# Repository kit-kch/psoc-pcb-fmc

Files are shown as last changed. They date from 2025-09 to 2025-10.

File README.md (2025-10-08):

# PSoC FMC Extension PCB

This repository contains schematic, layout and BOM for the PSoC FMC extension PCB.
The PCB provides all peripherals that are used to realize the [PSoC Audio Player](https://kch.dev/psoc).
It is primarily meant to be used with the Zedboard for FPGA prototyping, but it can also serve as a test board for the PSoC ASIC.

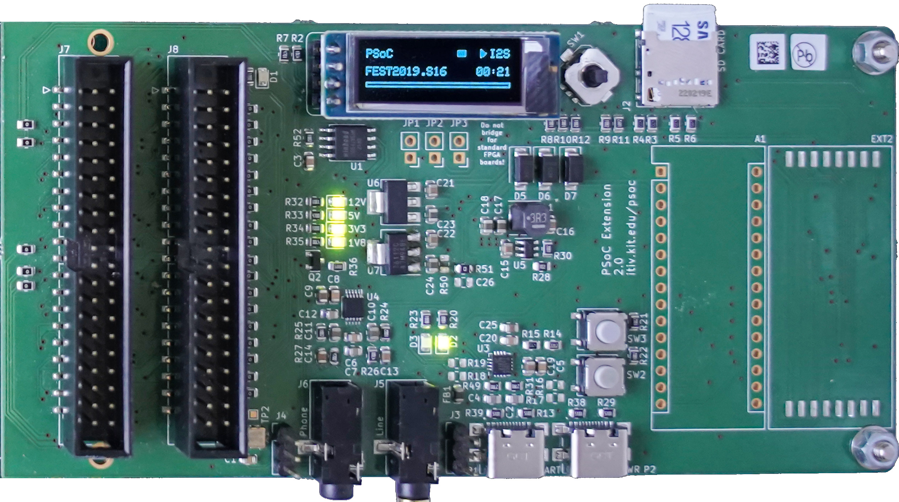
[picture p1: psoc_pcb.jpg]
PCB Render Image


The following features are provided by the PCB:
* 98.304 MHz oscillator ([XLH53V098.304000X](doc/REN_XL_Crystal_Oscillators_Datasheet_DST_20220302-1954959-1.pdf)) for SoC clock
* 64 MBit QSPI Flash ([W25Q64JVSSIM](doc/w25q64jv_dtr_revj_03272018_plus-1489809.pdf))
* USB/UART bridge ([CP2102N](doc/cp2102n_datasheet-1634912.pdf))
* 3 LEDs
* 2 [push buttons](doc/EVPBF.pdf)
* [5-way digital joystick](doc/SKRHAAE010.pdf)
* 128x32 [OLED display](https://www.waveshare.com/0.91inch-oled-module.htm) (I2C)
* I2S DAC with output filter networks ([CS4344-CZZR](doc/CS4344-45-48_F2.pdf))
* [3.5mm audio jack](doc/sj_352x_smt-1779397.pdf) for I2S DAC
* [3.5mm audio jack](doc/sj_352x_smt-1779397.pdf) directly connected to FMC
* [MicroSD card connector](doc/MOLEX_472192001_sd.pdf) (1-bit data line only)
* Power switch network: Power PCB from FMC 12V, power connector or UART usb connector
* 5V power regulator ([AP62300WU](doc/AP62300_AP62301_AP62300T.pdf))
* 3.3V power regulator (AMS1117-3.3)
* 1.8V power regulator (LM1117MPX-ADJ)
* Power indicator LEDs
* [USB-C connector](doc/usb4110.pdf) for UART
* [USB-C connector](doc/usb4110.pdf) for power
* [FMC LPC connector](doc/asp-134604-01-mkt-1546032.pdf) to connect to FPGA or ASIC
* 2 [40-pin pin headers](doc/SBH11-NBPC.pdf) for debugging of any signal
* Connector for future extensions (based on KiCAD RFM69HW footprint)
* Arduino-like connector for future extensions

For more details, see the [schematic](psoc.pdf):

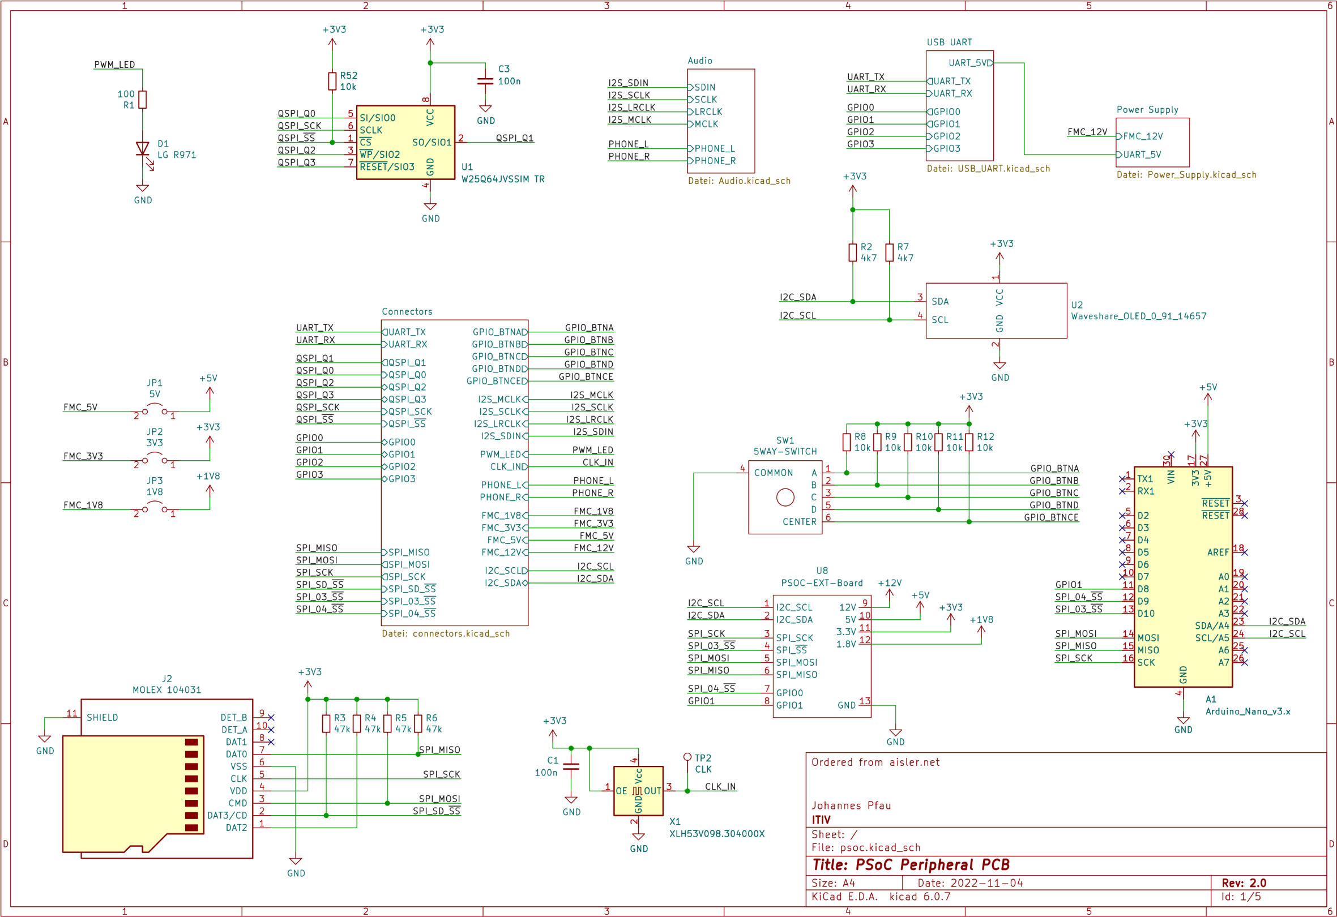
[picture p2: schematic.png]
PCB Schematic


## Ordering the PCBs

PCBs were ordered from [aisler.net](https://aisler.net) using the [fab.zip](fab.zip) file.
Make sure to use a stencil with 150µm thickness for proper FMC connector soldering.

## More Information and Documentation

* Project Website and Documentation: [kch.dev/psoc](https://kch.dev/psoc)
* Project Schematic: [psoc.pdf](psoc.pdf)

Additional documentation:
* [FMC Documentation](https://fmchub.github.io/appendix/VITA57_FMC_HPC_LPC_SIGNALS_AND_PINOUT.html)
* [USB-C Termination](https://community.cypress.com/t5/Knowledge-Base-Articles/Termination-Resistors-Required-for-the-USB-Type-C-Connector/ta-p/253544)
* [Audio TRS Standard](https://components101.com/connectors/35mm-audio-jack)

## Note and Limitations

### JTAG

* The board unfortunately does not provide convenient access to JTAG pins, although the debug header can be used.
  As a workaround, [psoc-pcb-jtag](https://github.com/kit-kch/psoc-pcb-jtag) can be connected to the USB header.

### Powering the IHP ASIC

The [IHP SG13G2 ASIC](https://github.com/IHP-GmbH/TO_Sep2025/pull/4) requires an 1.2V source instead of the 1.8V on this board.
Although the regulator on the board is adjustable, it can't go down to 1.2V.

As a simple solution, some parts can be replaced to provide 1.2V output:
* `U7` with `TLV76112DCYR` 1A 1.2V regulator
* `R51` with 0 Ohm (short)
* Remove `R50`
* Remove `C26`

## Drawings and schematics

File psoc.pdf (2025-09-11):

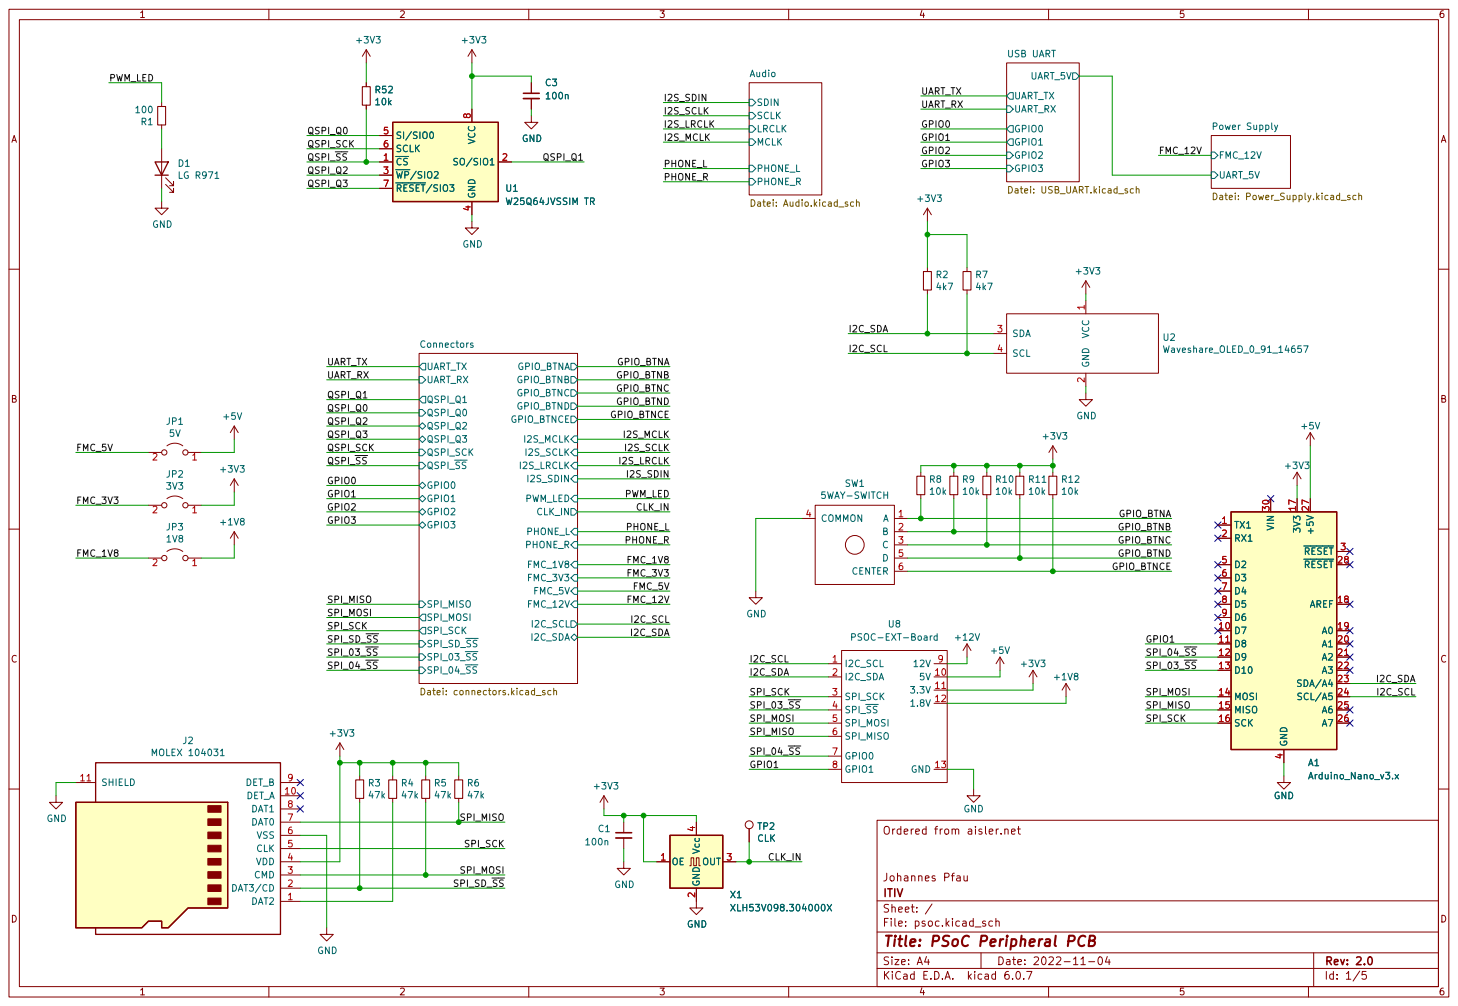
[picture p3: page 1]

4 SI/SIO0 5 SCLK 6 ~{RESET}/SIO3 7 VCC

12V 9 U8 PSOC-EXT-Board GND
I2C_SDA

Johannes Pfau Ordered from aisler.net

ITIV
File: psoc.kicad_sch Sheet: /
Id: 1/5 Title: PSoC Peripheral PCB

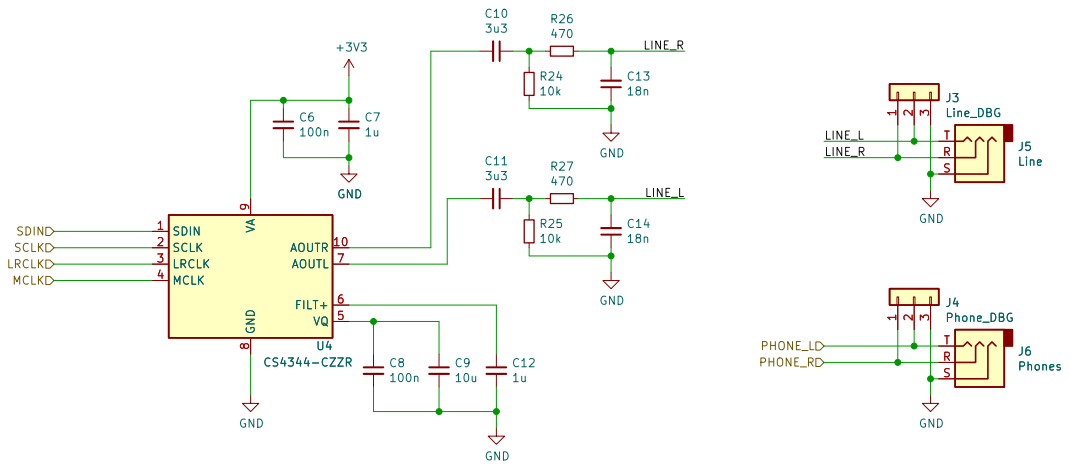
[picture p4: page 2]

LINE_L
File: Audio.kicad_sch Sheet: /Audio/ GND

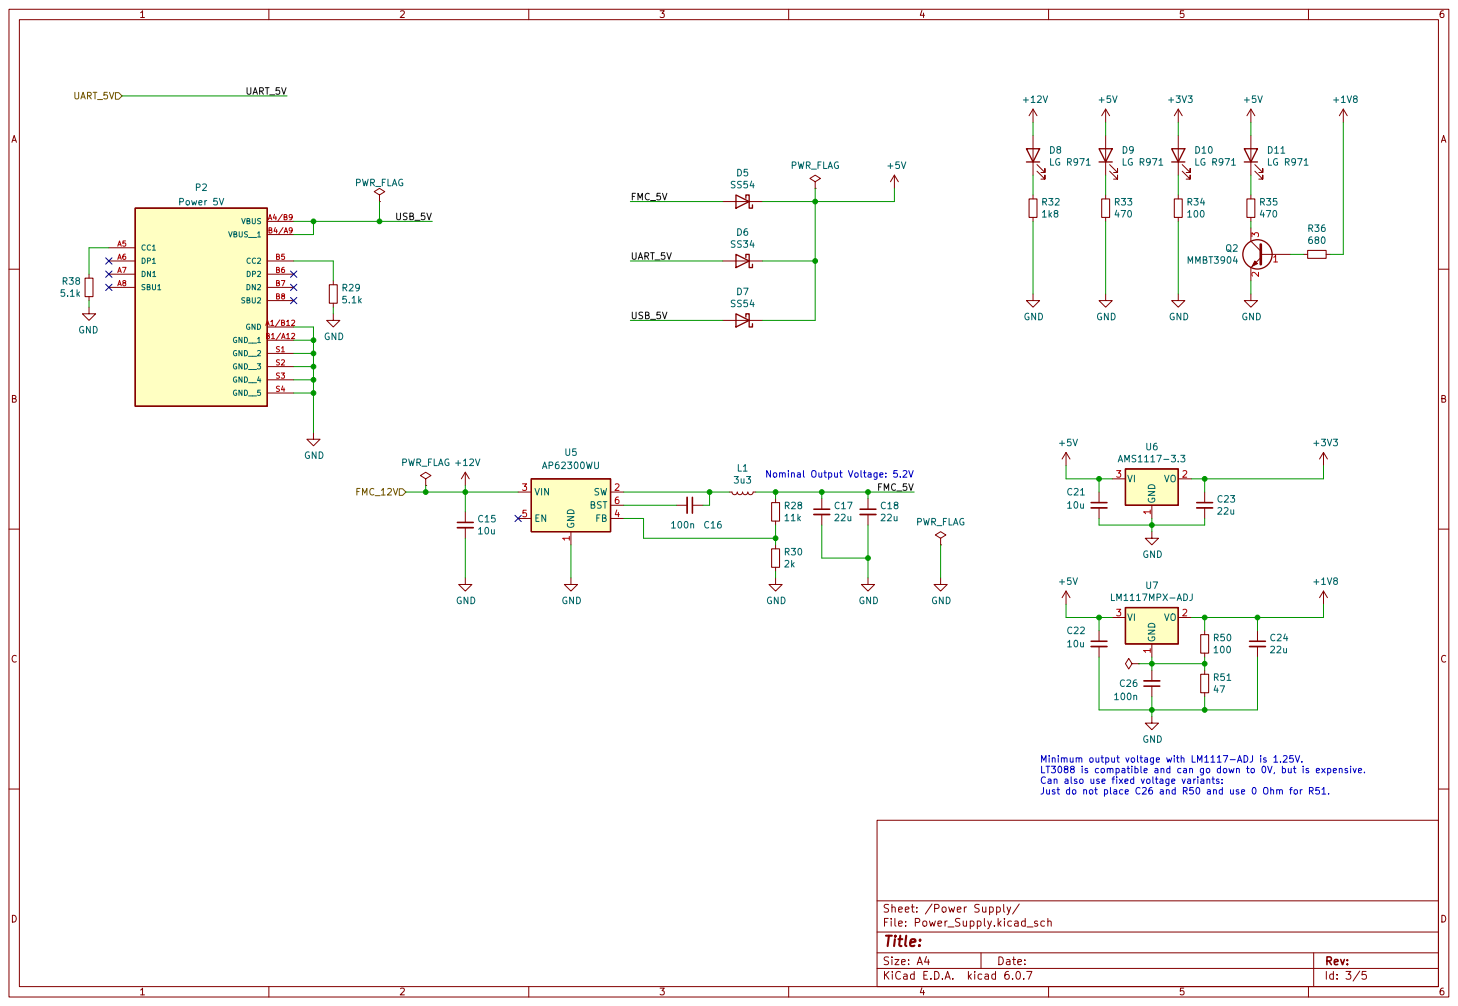
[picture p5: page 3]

1 SW 2 VIN 3 FB 4 EN 5 BST 6 U5 AP62300WU

Minimum output voltage with LM1117-ADJ is 1.25V.
LT3088 is compatible and can go down to 0V, but is expensive.
Can also use fixed voltage variants:
Just do not place C26 and R50 and use 0 Ohm for R51.

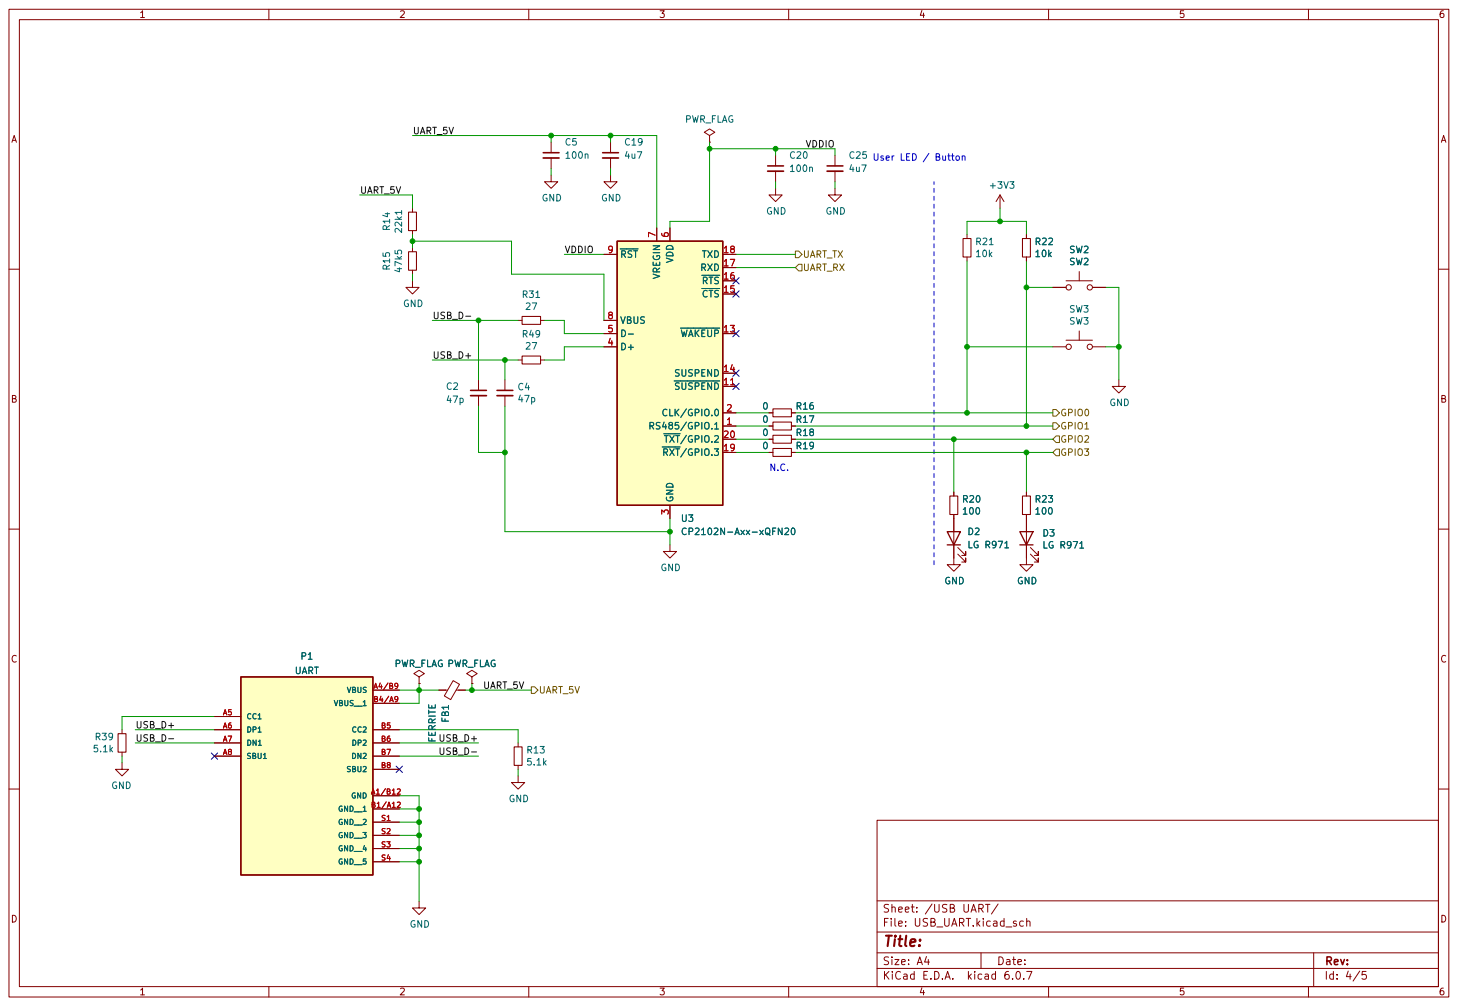
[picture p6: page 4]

7 VBUS 8 ~{RST} 9 P1 UART GND A1/B12 VBUS A4/B9 CC1 A5 DP1 A6 DN1 A7 SBU1 A8 GND__1 B1/A12 VBUS__1 B4/A9 CC2 B5 DP2 B6 DN2 B7 SBU2 B8 GND__2 S1 GND__3 S2 GND__4 S3 GND__5 S4

File: USB_UART.kicad_sch Sheet: /USB UART/ GND

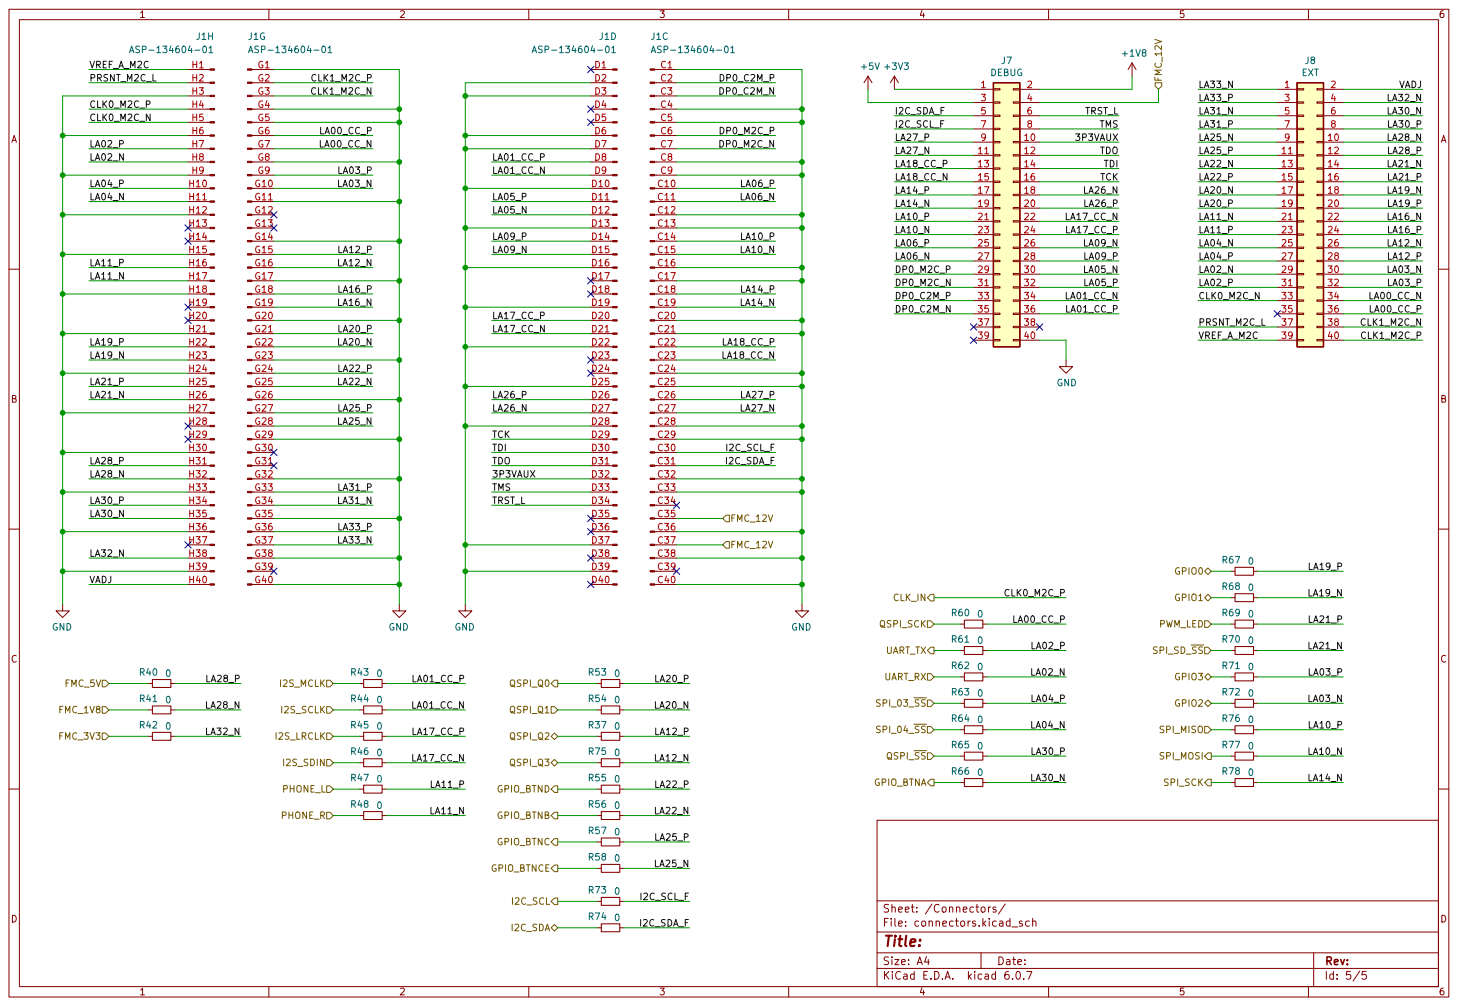
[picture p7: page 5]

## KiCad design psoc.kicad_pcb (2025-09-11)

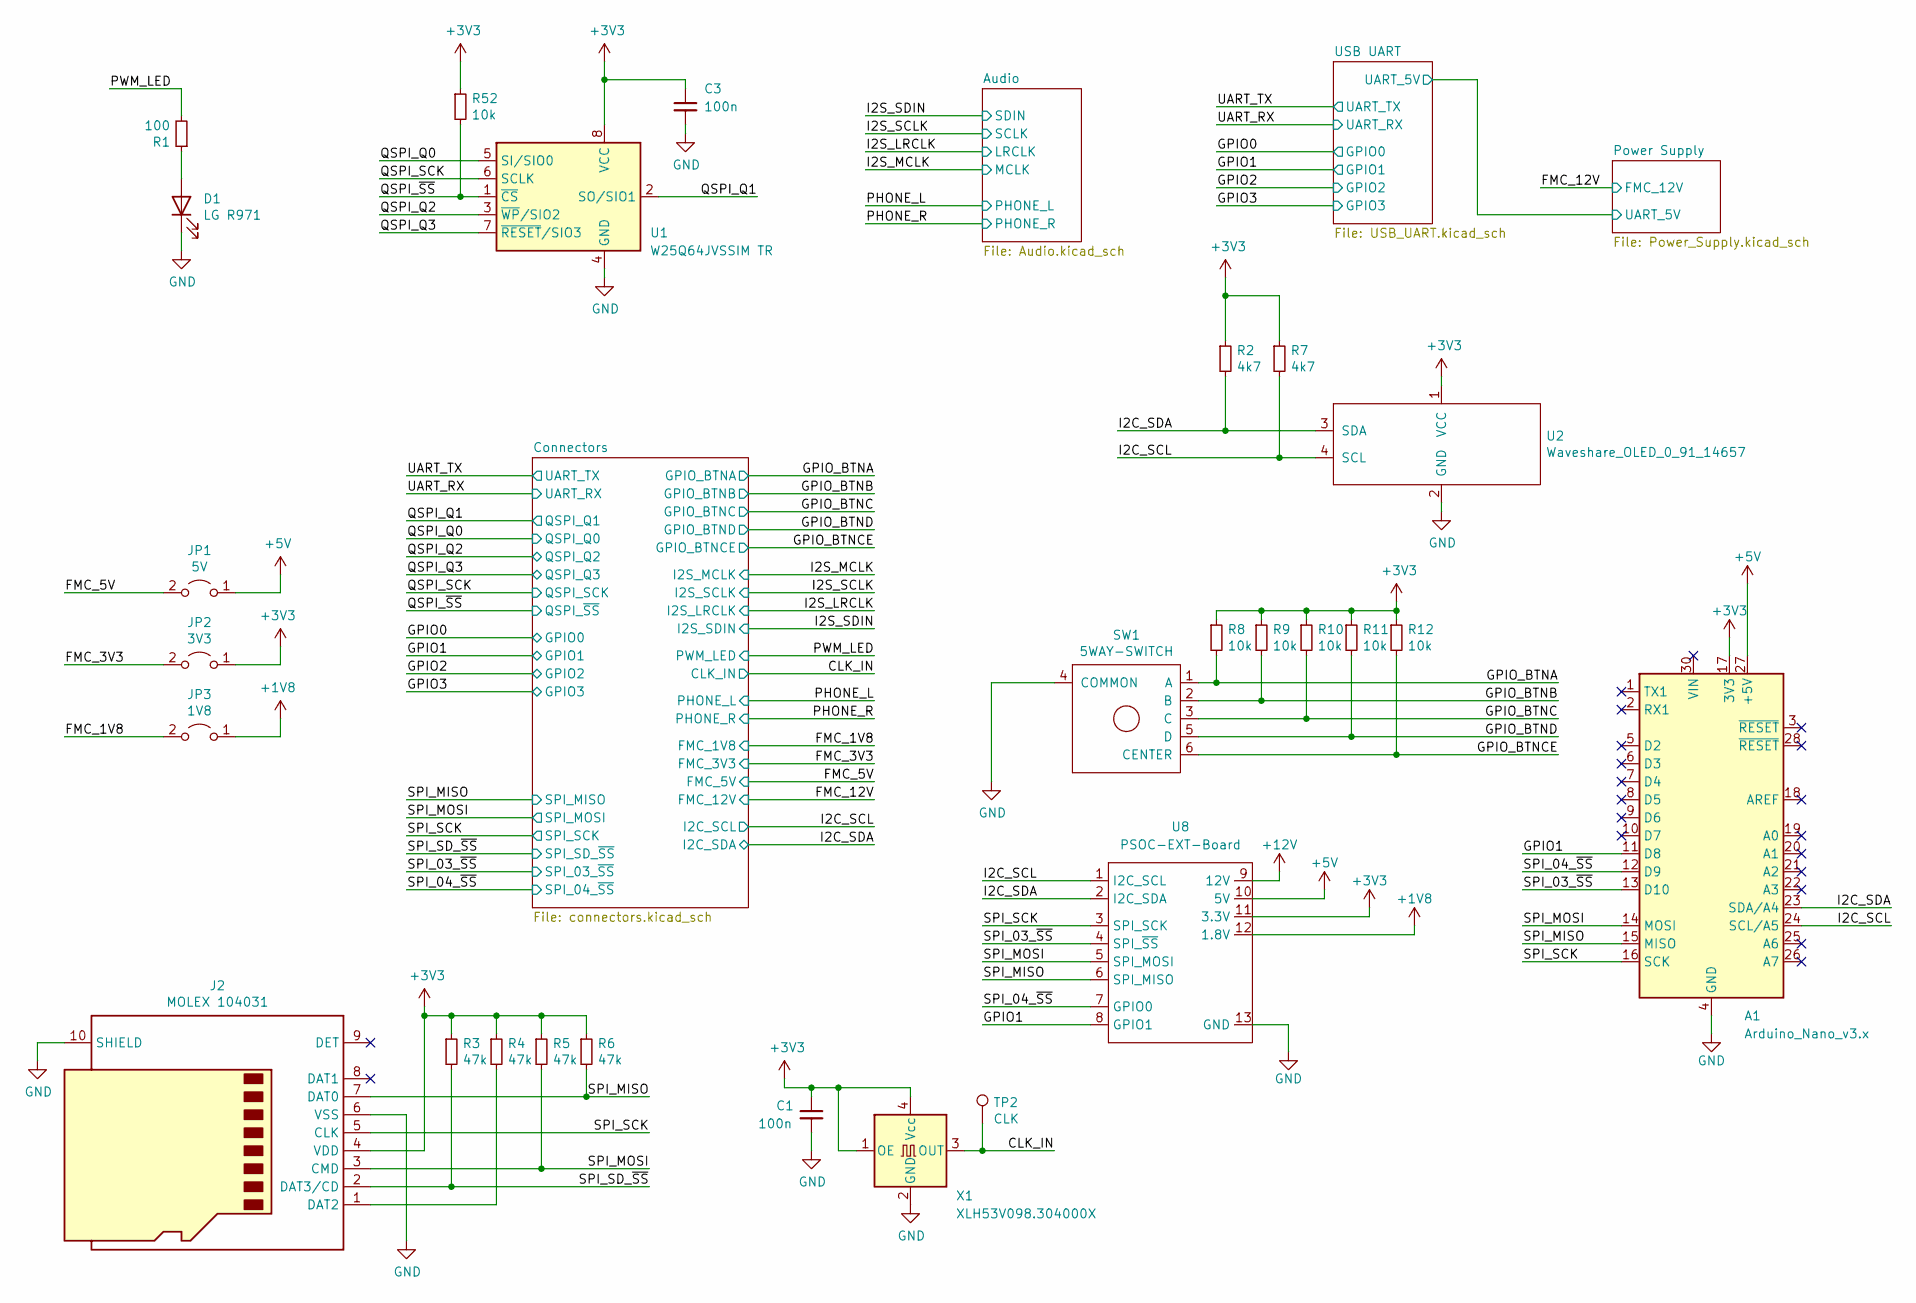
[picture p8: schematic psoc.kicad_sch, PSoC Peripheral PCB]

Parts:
A1: Arduino_Nano_v3.x; Arduino_Nano
C1, C3: 100n; C_0805_2012Metric; MPN 100nF 0805
D1: LG R971; LED_0805_2012Metric; MPN LG R971-KN-1
J2: MOLEX 104031; microSD_HC_Molex_104031-0811; MPN 1040310811
JP1: 5V; PinHeader_1x02_P2.54mm_Vertical; MPN 2302-6111TG
JP2: 3V3; PinHeader_1x02_P2.54mm_Vertical; MPN 2302-6111TG
JP3: 1V8; PinHeader_1x02_P2.54mm_Vertical; MPN 2302-6111TG
R1: 100; R_0805_2012Metric; MPN 0805 100
R2, R7: 4k7; R_0805_2012Metric; MPN 4k7 0805
R3, R4, R5, R6: 47k; R_0805_2012Metric; MPN 47k 0805
R8, R9, R10, R11, R12, R52: 10k; R_0805_2012Metric; MPN 10k 0805
SW1: 5WAY-SWITCH; SKRHAAE010; MPN SKRHAAE010
TP2: CLK; TestPoint_Pad_1.0x1.0mm
U1: W25Q64JVSSIM TR; SOIC-8_5.3x5.3mm_P1.27mm; MPN W25Q64JVSSIM TR
U2: Waveshare_OLED_0_91_14657; Waveshare_OLED_091
U8: PSOC-EXT-Board; PSOC_EXT_BOARD
X1: XLH53V098.304000X; Oscillator_SMD_Renesas_LGA-6_5x3.2mm_P1.25mm; MPN XLH53V098.304000X

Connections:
+1V8: JP3.1 (A), U8.12 (1.8V); also elsewhere on the board
+3V3: A1.17 (3V3), C1.1, C3.1, J2.4 (VDD), JP2.1 (A), R2.1, R3.1, R4.1, R5.1, R6.1, R7.1, R8.1, R9.1, R10.1, R11.1, R12.1, R52.1, U1.8 (VCC), U2.1 (VCC), U8.11 (3.3V), X1.1 (OE), X1.4 (Vcc); also elsewhere on the board
+5V: A1.27 (+5V), JP1.1 (A), U8.10 (5V); also elsewhere on the board
+12V: U8.9 (12V); also elsewhere on the board
/CLK_IN: TP2.1, X1.3 (OUT); also elsewhere on the board
/FMC_1V8: JP3.2 (B); also elsewhere on the board
/FMC_3V3: JP2.2 (B); also elsewhere on the board
/FMC_5V: JP1.2 (B); also elsewhere on the board
/GPIO1: A1.11 (D8), U8.8 (GPIO1); also elsewhere on the board
/GPIO_BTNA: R8.2, SW1.1 (A); also elsewhere on the board
/GPIO_BTNB: R9.2, SW1.2 (B); also elsewhere on the board
/GPIO_BTNC: R10.2, SW1.3 (C); also elsewhere on the board
/GPIO_BTNCE: R12.2, SW1.6 (CENTER); also elsewhere on the board
/GPIO_BTND: R11.2, SW1.5 (D); also elsewhere on the board
/I2C_SCL: A1.24 (SCL/A5), R7.2, U2.4 (SCL), U8.1 (I2C_SCL); also elsewhere on the board
/I2C_SDA: A1.23 (SDA/A4), R2.2, U2.3 (SDA), U8.2 (I2C_SDA); also elsewhere on the board
/PWM_LED: R1.2; also elsewhere on the board
/QSPI_Q0: U1.5 (SI/SIO0); also elsewhere on the board
/QSPI_Q1: U1.2 (SO/SIO1); also elsewhere on the board
/QSPI_Q2: U1.3 (~WP/SIO2); also elsewhere on the board
/QSPI_Q3: U1.7 (~RESET/SIO3); also elsewhere on the board
/QSPI_SCK: U1.6 (SCLK); also elsewhere on the board
/QSPI_~SS: R52.2, U1.1 (~CS); also elsewhere on the board
/SPI_03_~SS: A1.13 (D10), U8.4 (SPI_~SS); also elsewhere on the board
/SPI_04_~SS: A1.12 (D9), U8.7 (GPIO0); also elsewhere on the board
/SPI_MISO: A1.15 (MISO), J2.7 (DAT0), R6.2, U8.6 (SPI_MISO); also elsewhere on the board
/SPI_MOSI: A1.14 (MOSI), J2.3 (CMD), R5.2, U8.5 (SPI_MOSI); also elsewhere on the board
/SPI_SCK: A1.16 (SCK), J2.5 (CLK), U8.3 (SPI_SCK); also elsewhere on the board
/SPI_SD_~SS: J2.2 (DAT3/CD), R3.2; also elsewhere on the board
GND: A1.4 (GND), A1.29 (GND), C1.2, C3.2, D1.1 (K), J2.6 (VSS), J2.10 (SHIELD), J2.11 (SHIELD), SW1.4 (COMMON), U1.4 (GND), U2.2 (GND), U8.13 (GND), X1.2 (GND); also elsewhere on the board
unnamed: D1.2 (A), R1.1
unnamed: J2.1 (DAT2), R4.2

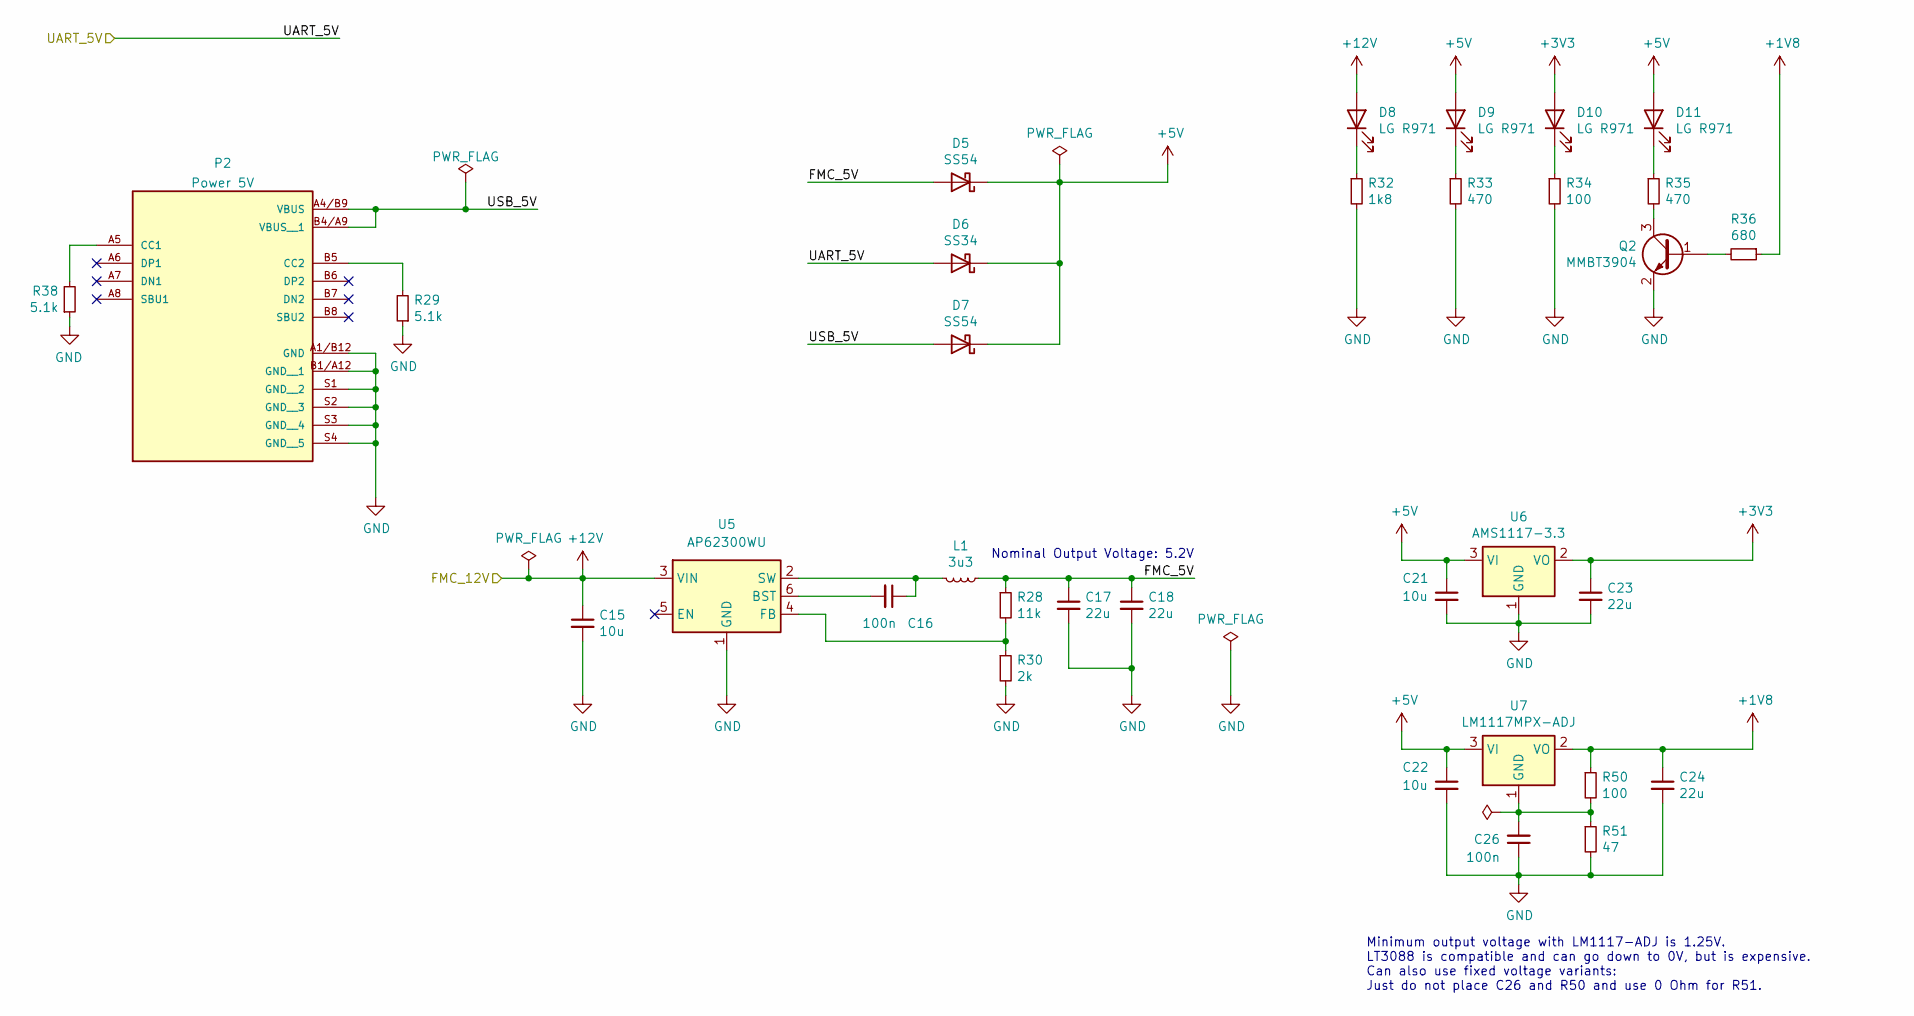
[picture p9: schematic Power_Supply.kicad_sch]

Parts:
C15, C21, C22: 10u; C_0805_2012Metric; MPN 10uF 0805 25V
C16, C26: 100n; C_0805_2012Metric; MPN 100nF 0805
C17, C18, C23, C24: 22u; C_0805_2012Metric; MPN 22uF 0805
D5, D7: SS54; D_SMA; MPN SS54
D6: SS34; D_SMA; MPN SS34
D8, D9, D10, D11: LG R971; LED_0805_2012Metric; MPN LG R971-KN-1
L1: 3u3; L_Taiyo-Yuden_NR-50xx; MPN NRS5040T3R3NMGJ
P2: Power 5V; GCT_USB4110-GF-A_REVB; MPN USB4110-GF-A
Q2: MMBT3904; SOT-23; MPN MMBT3904Q-7-F
R28: 11k; R_0805_2012Metric; MPN 11k 0805
R29, R38: 5.1k; R_0805_2012Metric; MPN 5k1 0805
R30: 2k; R_0805_2012Metric; MPN 2k 0805
R32: 1k8; R_0805_2012Metric; MPN 1k8 0805
R33, R35: 470; R_0805_2012Metric; MPN 0805 470
R34: 100; R_0805_2012Metric; MPN 0805 100
R36: 680; R_0805_2012Metric; MPN 0805 680
R50: 100; R_0805_2012Metric; MPN 100 0805
R51: 47; R_0805_2012Metric; MPN 47 0805
U5: AP62300WU; TSOT-23-6; MPN AP62301WU-7
U6: AMS1117-3.3; TO-252-3_TabPin2; MPN AZ1117IH-3.3TRG1
U7: LM1117MPX-ADJ; TO-252-3_TabPin2; MPN LM1117MPX-ADJNOPB

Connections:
+1V8: C24.1, R36.1, R50.1, U7.2 (VO); also elsewhere on the board
+3V3: C23.1, D10.2 (A), U6.2 (VO); also elsewhere on the board
+5V: C21.1, C22.1, D5.1 (K), D6.1 (K), D7.1 (K), D9.2 (A), D11.2 (A), U6.3 (VI), U7.3 (VI); also elsewhere on the board
+12V: C15.1, D8.2 (A), U5.3 (VIN); also elsewhere on the board
/Power Supply/FMC_5V: C17.1, C18.1, D5.2 (A), L1.1, R28.1
/Power Supply/UART_5V: D6.2 (A); also elsewhere on the board
/Power Supply/USB_5V: D7.2 (A), P2.A4/B9 (VBUS), P2.B4/A9 (VBUS__1)
GND: C15.2, C17.2, C18.2, C21.2, C22.2, C23.2, C24.2, C26.1, P2.A1/B12 (GND), P2.B1/A12 (GND__1), P2.S1 (GND__2), P2.S2 (GND__3), P2.S3 (GND__4), P2.S4 (GND__5), Q2.2 (E), R29.1, R30.2, R32.2, R33.2, R34.2, R38.1, R51.2, U5.1 (GND), U6.1 (GND); also elsewhere on the board
unnamed: C16.1, L1.2, U5.2 (SW)
unnamed: C16.2, U5.6 (BST)
unnamed: C26.2, R50.2, R51.1, U7.1 (GND)
unnamed: D8.1 (K), R32.1
unnamed: D9.1 (K), R33.1
unnamed: D10.1 (K), R34.1
unnamed: D11.1 (K), R35.1
unnamed: P2.A5 (CC1), R38.2
unnamed: P2.B5 (CC2), R29.2
unnamed: Q2.1 (B), R36.2
unnamed: Q2.3 (C), R35.2
unnamed: R28.2, R30.1, U5.4 (FB)

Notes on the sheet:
Minimum output voltage with LM1117-ADJ is 1.25V. LT3088 is compatible and can go down to 0V, but is expensive. Can also use fixed voltage variants: Just do not place C26 and R50 and use 0 Ohm for R51.
Nominal Output Voltage: 5.2V

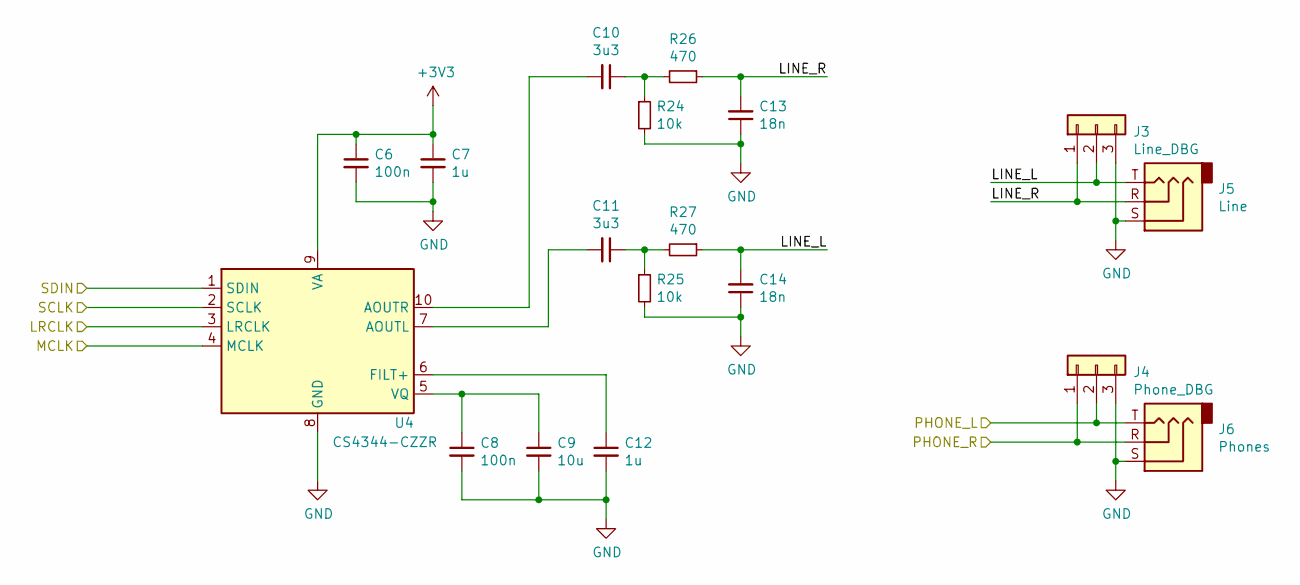
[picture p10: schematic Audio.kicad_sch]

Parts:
C6, C8: 100n; C_0805_2012Metric; MPN 100nF 0805
C7, C12: 1u; C_0805_2012Metric; MPN 1uF 0805
C9: 10u; C_0805_2012Metric; MPN 10uF 0805 25V
C10, C11: 3u3; C_0805_2012Metric; MPN 3.3uF 0805
C13, C14: 18n; C_0805_2012Metric; MPN 18nF 0805
J3: Line_DBG; PinHeader_1x03_P2.54mm_Vertical; MPN 2303-6111TG
J4: Phone_DBG; PinHeader_1x03_P2.54mm_Vertical; MPN 2303-6111TG
J5: Line; Jack_3.5mm_CUI_SJ-3523-SMT_Horizontal; MPN SJ-3523-SMT-TR
J6: Phones; Jack_3.5mm_CUI_SJ-3523-SMT_Horizontal; MPN SJ-3523-SMT-TR
R24, R25: 10k; R_0805_2012Metric; MPN 10k 0805
R26, R27: 470; R_0805_2012Metric; MPN 0805 470
U4: CS4344-CZZR; TSSOP-10_3x3mm_P0.5mm; MPN CS4344-CZZR

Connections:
+3V3: C6.1, C7.1, U4.9 (VA); also elsewhere on the board
/Audio/LINE_L: C14.2, J3.2, J5.T, R27.1
/Audio/LINE_R: C13.2, J3.1, J5.R, R26.1
/I2S_LRCLK: U4.3 (LRCLK); also elsewhere on the board
/I2S_MCLK: U4.4 (MCLK); also elsewhere on the board
/I2S_SCLK: U4.2 (SCLK); also elsewhere on the board
/I2S_SDIN: U4.1 (SDIN); also elsewhere on the board
/PHONE_L: J4.2, J6.T; also elsewhere on the board
/PHONE_R: J4.1, J6.R; also elsewhere on the board
GND: C6.2, C7.2, C8.2, C9.2, C12.2, C13.1, C14.1, J3.3, J4.3, J5.S, J6.S, R24.2, R25.2, U4.8 (GND); also elsewhere on the board
unnamed: C8.1, C9.1, U4.5 (VQ)
unnamed: C10.1, R24.1, R26.2
unnamed: C10.2, U4.10 (AOUTR)
unnamed: C11.1, R25.1, R27.2
unnamed: C11.2, U4.7 (AOUTL)
unnamed: C12.1, U4.6 (FILT+)

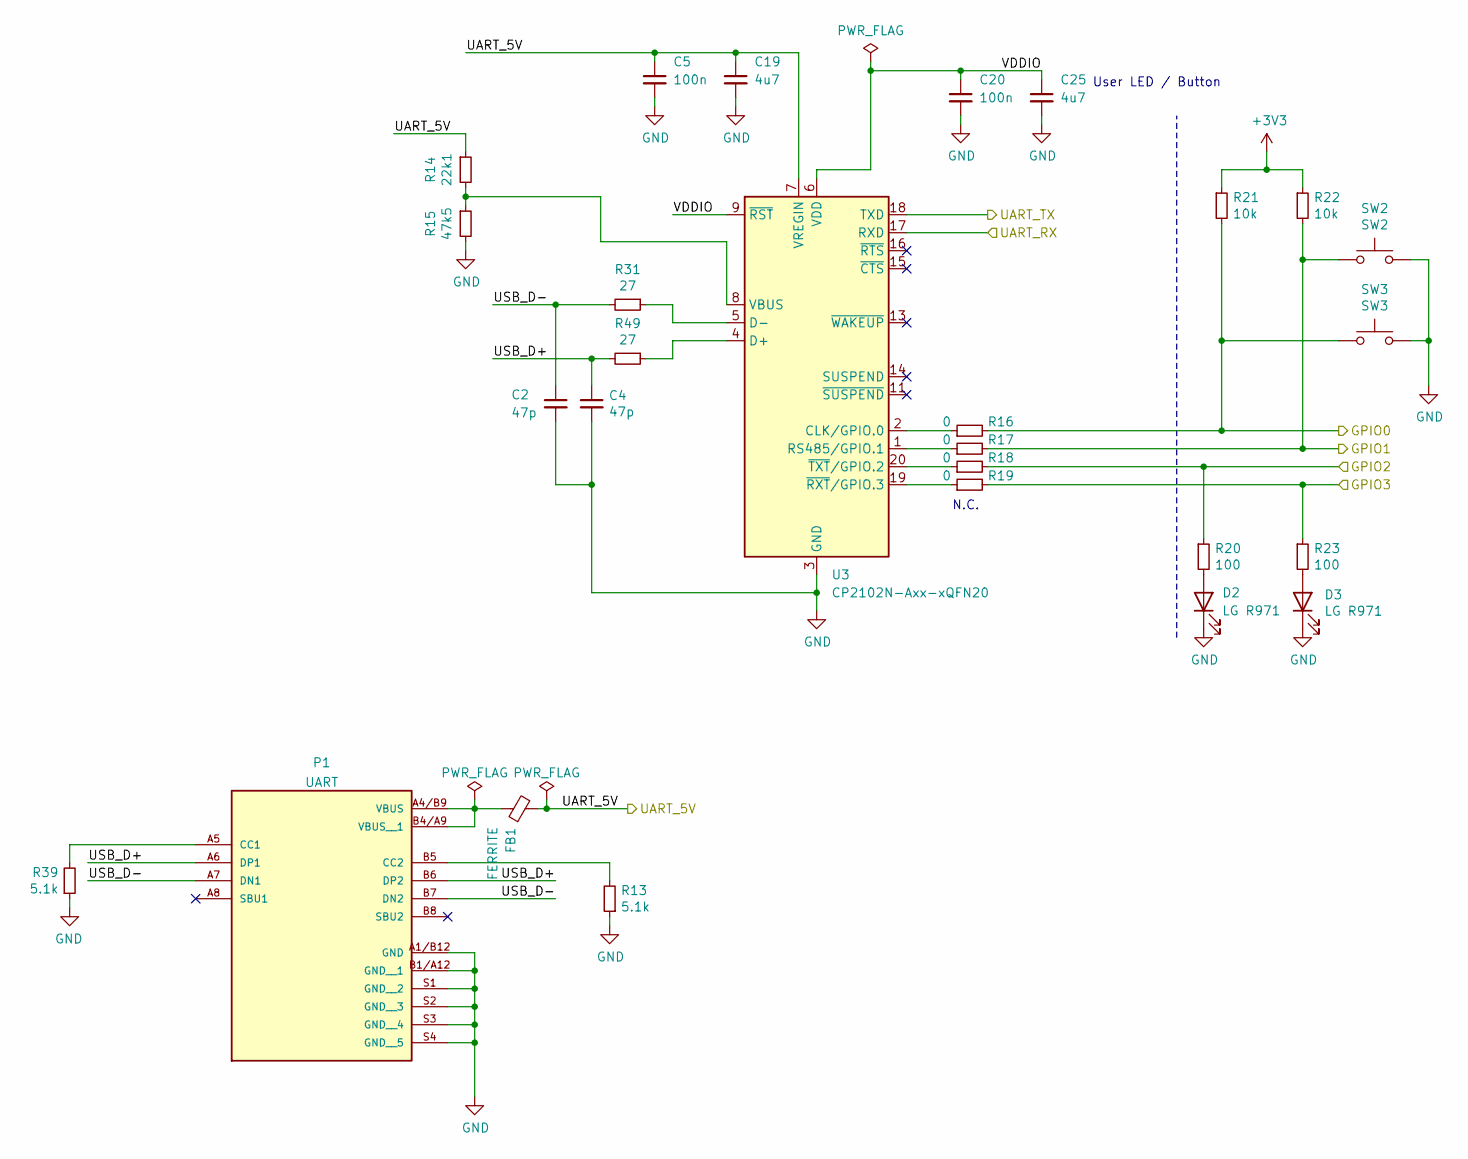
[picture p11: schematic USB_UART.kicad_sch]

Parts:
C2, C4: 47p; C_0805_2012Metric; MPN 47pF 0805
C5, C20: 100n; C_0805_2012Metric; MPN 100nF 0805
C19, C25: 4u7; C_0805_2012Metric; MPN 4.7uF 0805
D2, D3: LG R971; LED_0805_2012Metric; MPN LG R971-KN-1
FB1: FERRITE; L_0805_2012Metric; MPN ACML-0805-301-T
P1: UART; GCT_USB4110-GF-A_REVB; MPN USB4110-GF-A
R13, R39: 5.1k; R_0805_2012Metric; MPN 5k1 0805
R14: 22k1; R_0805_2012Metric; MPN 22k1 0805
R15: 47k5; R_0805_2012Metric; MPN 0805 47.5k
R16, R17, R18, R19: 0; R_0805_2012Metric; MPN 0805 0.0
R20, R23: 100; R_0805_2012Metric; MPN 0805 100
R21, R22: 10k; R_0805_2012Metric; MPN 10k 0805
R31, R49: 27; R_0805_2012Metric; MPN 0805 27
SW2: SW2; SW_SPST_EVPBF; MPN EVP-BF6C1A000
SW3: SW3; SW_SPST_EVPBF; MPN EVP-BF6C1A000
U3: CP2102N-Axx-xQFN20; SiliconLabs_QFN-20-1EP_3x3mm_P0.5mm_EP1.8x1.8mm; MPN CP2102N-A02-GQFN20

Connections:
+3V3: R21.1, R22.1; also elsewhere on the board
/GPIO0: R16.2, R21.2, SW3.1; also elsewhere on the board
/GPIO1: R17.2, R22.2, SW2.1; also elsewhere on the board
/GPIO2: R18.2, R20.1; also elsewhere on the board
/GPIO3: R19.2, R23.1; also elsewhere on the board
/Power Supply/UART_5V: C5.1, C19.1, FB1.2, R14.1, U3.7 (VREGIN); also elsewhere on the board
/UART_RX: U3.17 (RXD); also elsewhere on the board
/UART_TX: U3.18 (TXD); also elsewhere on the board
/USB UART/USB_D+: C4.1, P1.A6 (DP1), P1.B6 (DP2), R49.2
/USB UART/USB_D-: C2.1, P1.A7 (DN1), P1.B7 (DN2), R31.2
/USB UART/VDDIO: C20.1, C25.1, U3.6 (VDD), U3.9 (~RST)
GND: C2.2, C4.2, C5.2, C19.2, C20.2, C25.2, D2.1 (K), D3.1 (K), P1.A1/B12 (GND), P1.B1/A12 (GND__1), P1.S1 (GND__2), P1.S2 (GND__3), P1.S3 (GND__4), P1.S4 (GND__5), R13.1, R15.2, R39.1, SW2.2, SW3.2, U3.3 (GND), U3.12 (GND), U3.21 (GND); also elsewhere on the board
unnamed: D2.2 (A), R20.2
unnamed: D3.2 (A), R23.2
unnamed: FB1.1, P1.A4/B9 (VBUS), P1.B4/A9 (VBUS__1)
unnamed: P1.A5 (CC1), R39.2
unnamed: P1.B5 (CC2), R13.2
unnamed: R14.2, R15.1, U3.8 (VBUS)
unnamed: R16.1, U3.2 (CLK/GPIO.0)
unnamed: R17.1, U3.1 (RS485/GPIO.1)
unnamed: R18.1, U3.20 (~TXT/GPIO.2)
unnamed: R19.1, U3.19 (~RXT/GPIO.3)
unnamed: R31.1, U3.5 (D-)
unnamed: R49.1, U3.4 (D+)

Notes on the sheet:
User LED / Button
N.C.

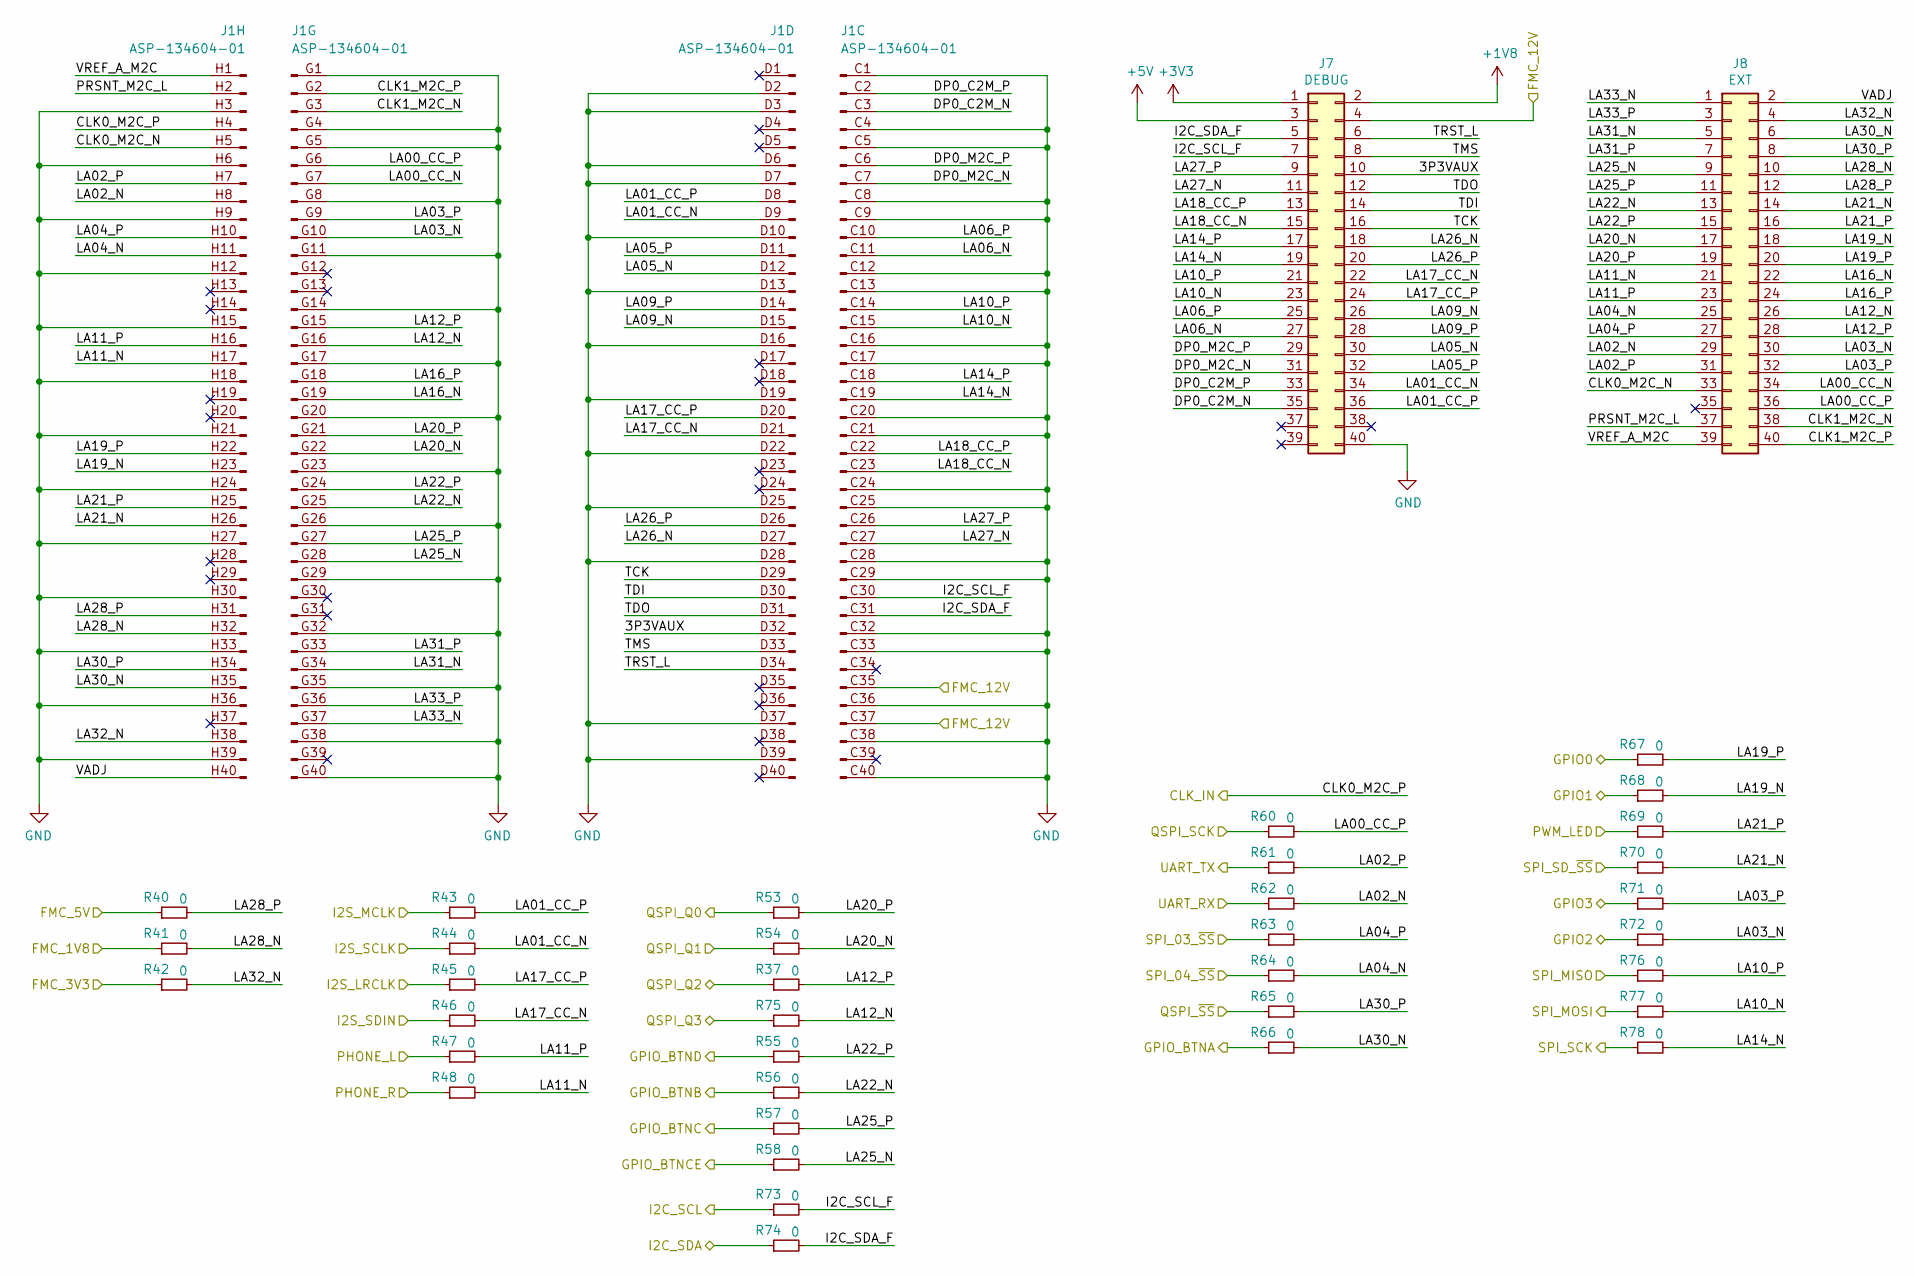
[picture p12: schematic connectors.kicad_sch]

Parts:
J1: ASP-134604-01; Samtec_FMC_ASP-134604-01_4x40_Vertical; MPN ASP-134604-01
J7: DEBUG; Pin-Header_ SBH11-NBPC-D20-SM-BK; MPN SBH11-NBPC-D20-SM-BK
J8: EXT; Pin-Header_ SBH11-NBPC-D20-SM-BK; MPN SBH11-NBPC-D20-SM-BK
R37, R40, R41, R42, R43, R44, R45, R46, R47, R48, R53, R54, R55, R56, R57, R58, R60, R61, R62, R63, R64, R65, R66, R67, R68, R69, R70, R71, R72, R73, R74, R75, R76, R77, R78: 0; R_0805_2012Metric; MPN 0805 0.0

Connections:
+1V8: J7.2; also elsewhere on the board
+3V3: J7.1; also elsewhere on the board
+5V: J7.3; also elsewhere on the board
+12V: J1.C35 (Pin_35), J1.C37 (Pin_37), J7.4; also elsewhere on the board
/CLK_IN: J1.H4 (Pin_4); also elsewhere on the board
/Connectors/3P3VAUX: J1.D32 (Pin_32), J7.10
/Connectors/CLK0_M2C_N: J1.H5 (Pin_5), J8.33
/Connectors/CLK1_M2C_N: J1.G3 (Pin_3), J8.38
/Connectors/CLK1_M2C_P: J1.G2 (Pin_2), J8.40
/Connectors/DP0_C2M_N: J1.C3 (Pin_3), J7.35
/Connectors/DP0_C2M_P: J1.C2 (Pin_2), J7.33
/Connectors/DP0_M2C_N: J1.C7 (Pin_7), J7.31
/Connectors/DP0_M2C_P: J1.C6 (Pin_6), J7.29
/Connectors/I2C_SCL_F: J1.C30 (Pin_30), J7.7, R73.2
/Connectors/I2C_SDA_F: J1.C31 (Pin_31), J7.5, R74.2
/Connectors/LA00_CC_N: J1.G7 (Pin_7), J8.34
/Connectors/LA00_CC_P: J1.G6 (Pin_6), J8.36, R60.2
/Connectors/LA01_CC_N: J1.D9 (Pin_9), J7.34, R44.2
/Connectors/LA01_CC_P: J1.D8 (Pin_8), J7.36, R43.2
/Connectors/LA02_N: J1.H8 (Pin_8), J8.29, R62.2
/Connectors/LA02_P: J1.H7 (Pin_7), J8.31, R61.2
/Connectors/LA03_N: J1.G10 (Pin_10), J8.30, R72.2
/Connectors/LA03_P: J1.G9 (Pin_9), J8.32, R71.2
/Connectors/LA04_N: J1.H11 (Pin_11), J8.25, R64.2
/Connectors/LA04_P: J1.H10 (Pin_10), J8.27, R63.2
/Connectors/LA05_N: J1.D12 (Pin_12), J7.30
/Connectors/LA05_P: J1.D11 (Pin_11), J7.32
/Connectors/LA06_N: J1.C11 (Pin_11), J7.27
/Connectors/LA06_P: J1.C10 (Pin_10), J7.25
/Connectors/LA09_N: J1.D15 (Pin_15), J7.26
/Connectors/LA09_P: J1.D14 (Pin_14), J7.28
/Connectors/LA10_N: J1.C15 (Pin_15), J7.23, R77.2
/Connectors/LA10_P: J1.C14 (Pin_14), J7.21, R76.2
/Connectors/LA11_N: J1.H17 (Pin_17), J8.21, R48.2
/Connectors/LA11_P: J1.H16 (Pin_16), J8.23, R47.2
/Connectors/LA12_N: J1.G16 (Pin_16), J8.26, R75.2
/Connectors/LA12_P: J1.G15 (Pin_15), J8.28, R37.2
/Connectors/LA14_N: J1.C19 (Pin_19), J7.19, R78.2
/Connectors/LA14_P: J1.C18 (Pin_18), J7.17
/Connectors/LA16_N: J1.G19 (Pin_19), J8.22
/Connectors/LA16_P: J1.G18 (Pin_18), J8.24
/Connectors/LA17_CC_N: J1.D21 (Pin_21), J7.22, R46.2
/Connectors/LA17_CC_P: J1.D20 (Pin_20), J7.24, R45.2
/Connectors/LA18_CC_N: J1.C23 (Pin_23), J7.15
/Connectors/LA18_CC_P: J1.C22 (Pin_22), J7.13
/Connectors/LA19_N: J1.H23 (Pin_23), J8.18, R68.2
/Connectors/LA19_P: J1.H22 (Pin_22), J8.20, R67.2
/Connectors/LA20_N: J1.G22 (Pin_22), J8.17, R54.2
/Connectors/LA20_P: J1.G21 (Pin_21), J8.19, R53.2
/Connectors/LA21_N: J1.H26 (Pin_26), J8.14, R70.2
/Connectors/LA21_P: J1.H25 (Pin_25), J8.16, R69.2
/Connectors/LA22_N: J1.G25 (Pin_25), J8.13, R56.2
/Connectors/LA22_P: J1.G24 (Pin_24), J8.15, R55.2
/Connectors/LA25_N: J1.G28 (Pin_28), J8.9, R58.2
/Connectors/LA25_P: J1.G27 (Pin_27), J8.11, R57.2
/Connectors/LA26_N: J1.D27 (Pin_27), J7.18
/Connectors/LA26_P: J1.D26 (Pin_26), J7.20
/Connectors/LA27_N: J1.C27 (Pin_27), J7.11
/Connectors/LA27_P: J1.C26 (Pin_26), J7.9
/Connectors/LA28_N: J1.H32 (Pin_32), J8.10, R41.2
/Connectors/LA28_P: J1.H31 (Pin_31), J8.12, R40.2
/Connectors/LA30_N: J1.H35 (Pin_35), J8.6, R66.2
/Connectors/LA30_P: J1.H34 (Pin_34), J8.8, R65.2
/Connectors/LA31_N: J1.G34 (Pin_34), J8.5
/Connectors/LA31_P: J1.G33 (Pin_33), J8.7
/Connectors/LA32_N: J1.H38 (Pin_38), J8.4, R42.2
/Connectors/LA33_N: J1.G37 (Pin_37), J8.1
/Connectors/LA33_P: J1.G36 (Pin_36), J8.3
/Connectors/PRSNT_M2C_L: J1.H2 (Pin_2), J8.37
/Connectors/TCK: J1.D29 (Pin_29), J7.16
/Connectors/TDI: J1.D30 (Pin_30), J7.14
/Connectors/TDO: J1.D31 (Pin_31), J7.12
/Connectors/TMS: J1.D33 (Pin_33), J7.8
/Connectors/TRST_L: J1.D34 (Pin_34), J7.6
/Connectors/VADJ: J1.H40 (Pin_40), J8.2
/Connectors/VREF_A_M2C: J1.H1 (Pin_1), J8.39
/FMC_1V8: R41.1; also elsewhere on the board
/FMC_3V3: R42.1; also elsewhere on the board
/FMC_5V: R40.1; also elsewhere on the board
/GPIO0: R67.1; also elsewhere on the board
/GPIO1: R68.1; also elsewhere on the board
/GPIO2: R72.1; also elsewhere on the board
/GPIO3: R71.1; also elsewhere on the board
/GPIO_BTNA: R66.1; also elsewhere on the board
/GPIO_BTNB: R56.1; also elsewhere on the board
/GPIO_BTNC: R57.1; also elsewhere on the board
/GPIO_BTNCE: R58.1; also elsewhere on the board
/GPIO_BTND: R55.1; also elsewhere on the board
/I2C_SCL: R73.1; also elsewhere on the board
/I2C_SDA: R74.1; also elsewhere on the board
/I2S_LRCLK: R45.1; also elsewhere on the board
/I2S_MCLK: R43.1; also elsewhere on the board
/I2S_SCLK: R44.1; also elsewhere on the board
/I2S_SDIN: R46.1; also elsewhere on the board
/PHONE_L: R47.1; also elsewhere on the board
/PHONE_R: R48.1; also elsewhere on the board
/PWM_LED: R69.1; also elsewhere on the board
/QSPI_Q0: R53.1; also elsewhere on the board
/QSPI_Q1: R54.1; also elsewhere on the board
/QSPI_Q2: R37.1; also elsewhere on the board
/QSPI_Q3: R75.1; also elsewhere on the board
/QSPI_SCK: R60.1; also elsewhere on the board
/QSPI_~SS: R65.1; also elsewhere on the board
/SPI_03_~SS: R63.1; also elsewhere on the board
/SPI_04_~SS: R64.1; also elsewhere on the board
/SPI_MISO: R76.1; also elsewhere on the board
/SPI_MOSI: R77.1; also elsewhere on the board
/SPI_SCK: R78.1; also elsewhere on the board
/SPI_SD_~SS: R70.1; also elsewhere on the board
/UART_RX: R62.1; also elsewhere on the board
/UART_TX: R61.1; also elsewhere on the board
GND: J1.C1 (Pin_1), J1.C4 (Pin_4), J1.C5 (Pin_5), J1.C8 (Pin_8), J1.C9 (Pin_9), J1.C12 (Pin_12), J1.C13 (Pin_13), J1.C16 (Pin_16), J1.C17 (Pin_17), J1.C20 (Pin_20), J1.C21 (Pin_21), J1.C24 (Pin_24), J1.C25 (Pin_25), J1.C28 (Pin_28), J1.C29 (Pin_29), J1.C32 (Pin_32), J1.C33 (Pin_33), J1.C36 (Pin_36), J1.C38 (Pin_38), J1.C40 (Pin_40), J1.D2 (Pin_2), J1.D3 (Pin_3), J1.D6 (Pin_6), J1.D7 (Pin_7), J1.D10 (Pin_10), J1.D13 (Pin_13), J1.D16 (Pin_16), J1.D19 (Pin_19), J1.D22 (Pin_22), J1.D25 (Pin_25), J1.D28 (Pin_28), J1.D37 (Pin_37), J1.D39 (Pin_39), J1.G1 (Pin_1), J1.G4 (Pin_4), J1.G5 (Pin_5), J1.G8 (Pin_8), J1.G11 (Pin_11), J1.G14 (Pin_14), J1.G17 (Pin_17), J1.G20 (Pin_20), J1.G23 (Pin_23), J1.G26 (Pin_26), J1.G29 (Pin_29), J1.G32 (Pin_32), J1.G35 (Pin_35), J1.G38 (Pin_38), J1.G40 (Pin_40), J1.H3 (Pin_3), J1.H6 (Pin_6), J1.H9 (Pin_9), J1.H12 (Pin_12), J1.H15 (Pin_15), J1.H18 (Pin_18), J1.H21 (Pin_21), J1.H24 (Pin_24), J1.H27 (Pin_27), J1.H30 (Pin_30), J1.H33 (Pin_33), J1.H36 (Pin_36), J1.H39 (Pin_39), J7.40; also elsewhere on the board

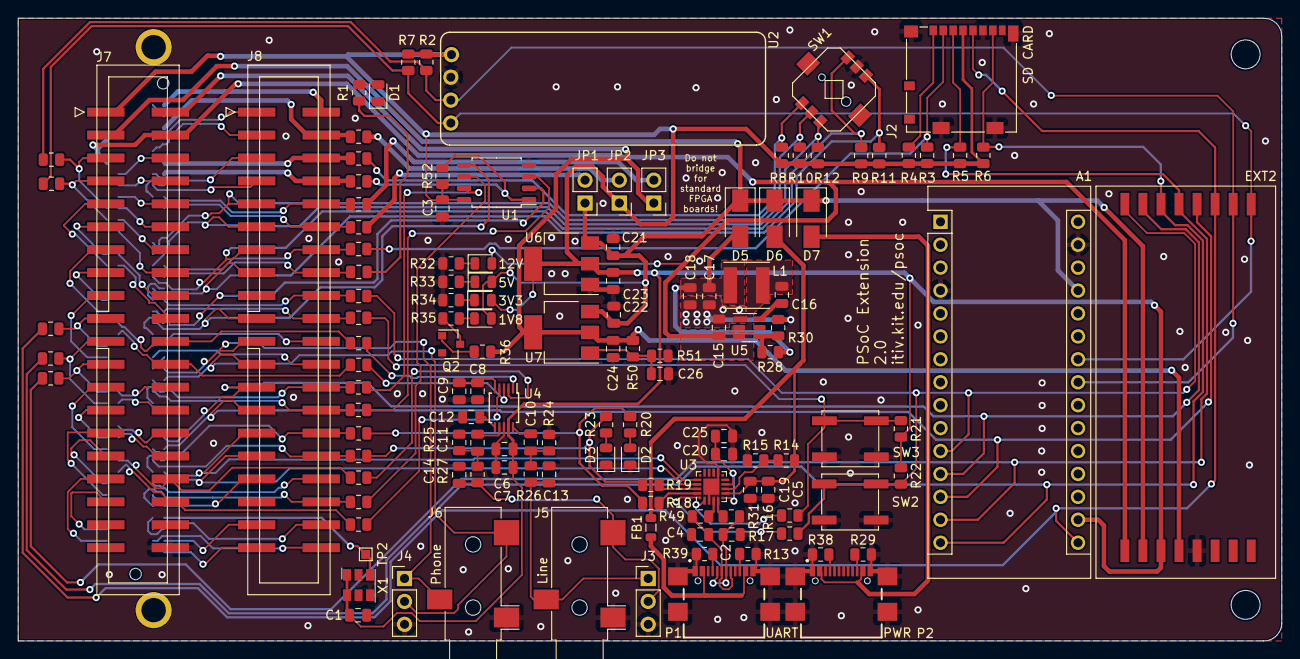
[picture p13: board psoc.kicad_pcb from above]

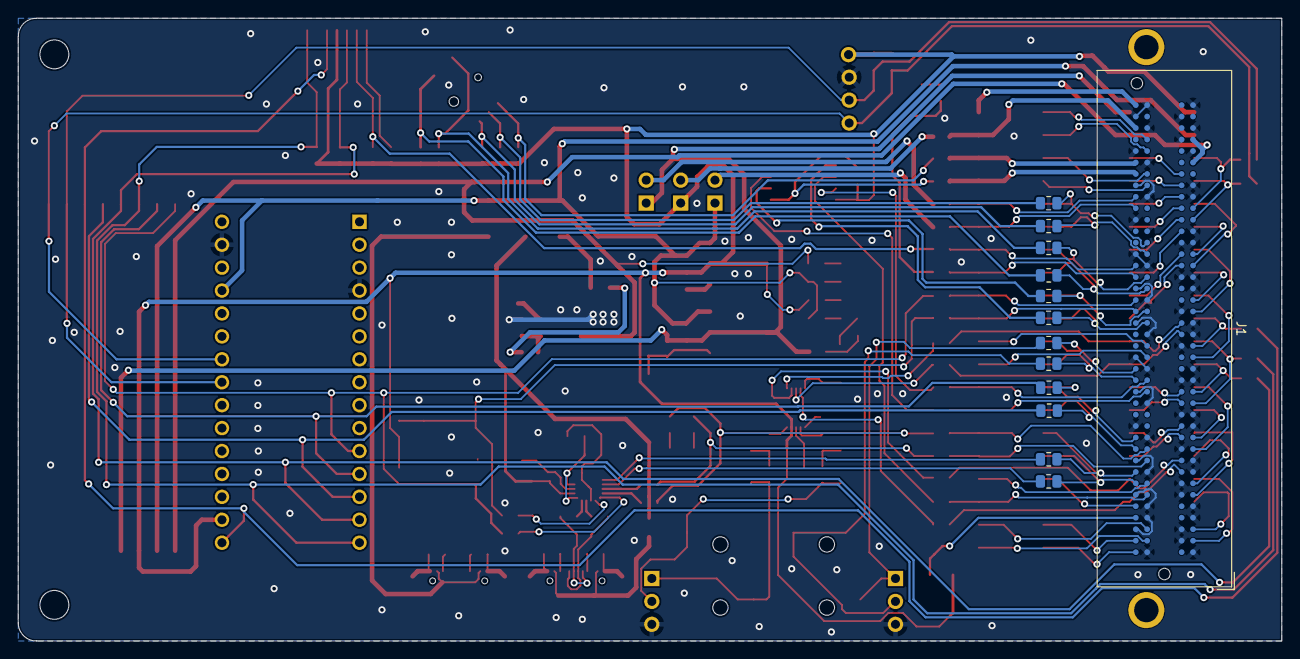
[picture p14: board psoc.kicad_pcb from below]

Board: 2 copper layers, 140.0 x 69.0 mm, 143 parts (13 on the bottom side), 152 nets.

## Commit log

2025-09-11 Public release
    [Audio.kicad_sch, Power_Supply.kicad_sch, USB_UART.kicad_sch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]
2025-10-08 Use picture of board instead of incomplete render image
